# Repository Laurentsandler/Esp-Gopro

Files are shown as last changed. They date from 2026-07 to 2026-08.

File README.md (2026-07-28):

# ESP32-P4 GO-Pro


## Overview

A compact, 3D-printed, battery-powered portable camera based on the Waveshare ESP32-P4 module.

**Motivation:**
I wanted to build a small action camera that can record me biking, among other cool stuff. I initally wanted to make a custom pcb, but the esp32 p4 is not yet available for pcba assembly.

## Usage

1. Connect the battery to the charger board, and connect the charger board to the mainboard.
2. Press the flex boot button to capture photos or start/stop recording.
3. Recharge using the USB-C port(on the charger board).

---

## Hardware & CAD

The custom enclosure was designed in Onshape. 

* **CAD Files:** https://cad.onshape.com/documents/a52dcf8d564a68f7811ecbec/w/4524fd8eb7e4bb6c92c5f085/e/23b7f0b571128349549216fd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

### Images

 **3D Model Assembly:** 

 **Case Details:** 

 **Wiring Diagram:** 
 
---

## Assembly Instructions

 1. To print the case, use a 0.2 mm layer height. You can use any material, but PLA or PLA silk is preferred due to its dimensional accuracy. With 15% infill being enough for structural integrity. 

 2. To assemble the device, first wire all of the components together as shown in the wiring diagram making sure to carefully connect the camera with its ribbon connector into the camera connection slot on the main board then push the camera into its press-fit hole and push in the main ESP32-P4 board on top of it. you may then use tape or double-sided tape to secure the battery to the main board and to push the small charging board into its USB-C hole. This is enough to hold it down. Then finally, you may snap on the back lid. 
 
---

## Bill of Materials (BOM)

A complete `bom.csv` is included in the repository (`docs/BOM.csv`). Primary components include:

| Component | Description | Qty | Price (USD) | Source |
| :--- | :--- | :--- | :--- | :--- |
| **Microcontroller** | Waveshare ESP32-P4 Module (w/ camera connector) | 1 | ~$21.89 | [Amazon](https://amzn.eu/d/0bZVOaVJ) |
| **Camera** | Compatible Camera Module | 1 | ~$9.44 | [AliExpress](https://fr.aliexpress.com/item/1005004540834095.html) |
| **Battery** | LiPo Battery | 1 | ~$9.67 | [AliExpress](https://fr.aliexpress.com/item/1005009589383276.html) |
| **Power Management** | Battery Charging Module | 1 | ~$1.01 | [AliExpress](https://fr.aliexpress.com/item/1005005037876729.html) |

---

## Firmware & Software

The firmware targets the ESP-IDF framework directly (not Arduino — ESP32-P4 Arduino/PlatformIO-Arduino support is still unstable, Espressif itself recommends ESP-IDF for this chip at this stage). It's built with [PlatformIO](https://platformio.org/), which wraps ESP-IDF's build system for you.

**Prerequisites:**
* [PlatformIO](https://platformio.org/install) (CLI or the VS Code extension)
* That's it locally — PlatformIO downloads the ESP-IDF toolchain itself on first build.

**Dependencies:**
This project uses Espressif's official camera/video stack for the ESP32-P4, declared in [`src/idf_component.yml`](Firmware/src/idf_component.yml) and pulled automatically by the IDF Component Manager on first build (no manual download needed):
* [`espressif/esp_video`](https://components.espressif.com/components/espressif/esp_video) — V4L2-compatible camera driver framework for the ESP32-P4's MIPI-CSI interface. Transitively brings in `esp_cam_sensor` (OV5647 sensor driver), `esp_ipa` (image processing/AE/AWB), and `esp_sccb_intf` (camera control bus).
* [`espressif/esp_h264`](https://components.espressif.com/components/espressif/esp_h264) — hardware-accelerated H.264 encoder, used to encode video on the fly while recording.
* Everything else (FATFS, SDMMC host driver, GPIO, deep sleep) ships as part of ESP-IDF itself — no extra install.

**Building & flashing:**
```bash
cd Firmware
pio run              # build
pio run -t upload    # flash over USB-C
pio device monitor    # serial log at 115200 baud
```

**How it works:** the board deep-sleeps between button presses to save battery. A single click on BOOT starts recording (click again to stop); three clicks within 800 ms takes a photo. See the comment block at the top of `src/main.cpp` for the handful of hardware-specific details (exact button GPIO, deep-sleep wakeup API) worth double-checking against your specific board revision before you rely on it.

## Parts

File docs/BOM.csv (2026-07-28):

Component | Description | Quantity | Price (USD) | Link
Microcontroller | Waveshare ESP32-P4 module with camera connector | 1 | 21.89 | https://amzn.eu/d/0bZVOaVJ
Camera | Camera module | 1 | 9.44 | https://fr.aliexpress.com/item/1005004540834095.html?mp=1
Battery | LiPo Battery | 1 | 9.67 | https://fr.aliexpress.com/item/1005009589383276.html?mp=1
Power Management | Battery charging module | 1 | 1.10 | https://fr.aliexpress.com/item/1005005037876729.html?mp=1

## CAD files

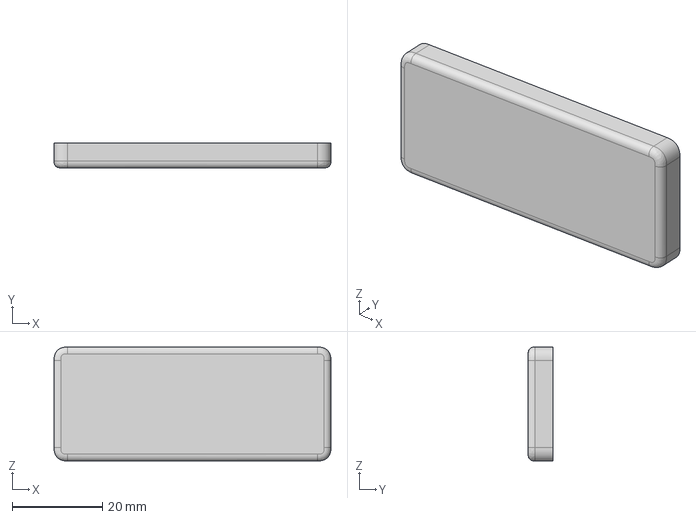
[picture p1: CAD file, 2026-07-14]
CAD/Lid.step
61.5 x 5.50 x 25.3 mm

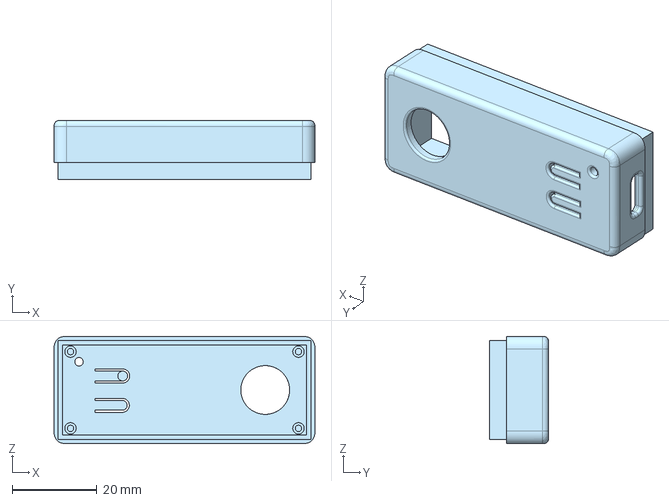
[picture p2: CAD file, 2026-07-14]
CAD/Case.step
61.5 x 14.0 x 25.3 mm

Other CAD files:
CAD/Case.stl
CAD/Lid.stl

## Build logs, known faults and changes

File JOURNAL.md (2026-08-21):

---

title: "DIY ESP32-P4 GoPro"
author: "Laurent Sandler"
description: "Development journal for a DIY ESP32-P4 GoPro"
created_at: "2026-06-19"
------------------------

# June 19: Created the concept and picked parts

Why the ESP32-P4 at all

I picked the P4 over the ESP32-S3 because I needed the ability to record video at a usable frame rate and quality, this requires a hardware video encoder and well as MIPI_CSI input, This is enough for video at 1080p30. The tradeoff i'm going to have the accept is no native wifi support without a sister ESP32-C6 chip.

The custom PCB endeavor

My first plan was a custom PCB with a bare ESP32-P4 module, so I could put the camera connector, charger, and battery management on a single board sized exactly to the case. I spent about ~10 minutes in JLCPCB's parts library searching, before I found out that that the ESP32-P4 isn't stocked for assembly yet.
and dealing with soldering under pcb pins is a headache, so I had to resort to a prebuilt module.

I found this Waveshare ESP32-P4 module with a camera connector.

Waveshare ESP32-P4 module

Finding a suitable camera was trickier, as this board does not have a standard OV5640 connector, it uses one similar to the one on a raspberry pi 02w. So I needed a compatible camera.

Camera

For the battery, I wanted it to fit directly behind the footprint of the main board. I found one that should give me approximately 1.5–2 hours of runtime at 1080p @ 30 FPS.

Battery

I also needed a battery charging module.

Battery charging module

**Total time spent:** 1 hour

# June 19: Designed the case

I designed the case in Onshape, with flex buttons for the reset and boot buttons. The boot button will serve as the only interactive button. I also added holes for the onboard microphone, camera, and USB-C charging port, as well as a snap-on lid. Rather than mounting physical switches, I made the reset and boot buttons as hinge flexures in the case wall, which are thin sections of plastic that bend enough to press the board's onboard tactile switches.

The boot button doubles as the only user control: start/stop recording, and to take photos. Reset stays the same. The chip is kept in a low power state until the button is pressed to start recording or too take a photo.

Case design

Case design

Case design

Case design

**Total time spent:** 4.5 hours

# August 7: Created the Git repository

I spent some time documenting everything about the project and build inside the README file in the repository. I also uploaded all of the files from Onshape, as well as the code. I created a BOM and drew a wiring diagram.

Wiring diagram

Project files

**Total time spent:** 2.5 hours

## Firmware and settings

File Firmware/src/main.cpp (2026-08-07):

#include <stdio.h>
#include <string.h>
#include <fcntl.h>
#include <unistd.h>
#include <sys/ioctl.h>

#include "freertos/FreeRTOS.h"
#include "freertos/task.h"

#include "esp_log.h"
#include "esp_err.h"
#include "esp_sleep.h"
#include "esp_timer.h"
#include "esp_heap_caps.h"
#include "driver/gpio.h"

#include "esp_vfs_fat.h"
#include "sdmmc_cmd.h"
#include "driver/sdmmc_host.h"

#include "linux/videodev2.h"   // V4L2 types/ioctls - esp_video is V4L2-compatible
#include "esp_video_init.h"    // board/sensor bring-up -> registers /dev/videoX
#include "esp_h264_enc.h"      // hardware H.264 encoder

// ---------------------------------------------------------------------------
// Config
// ---------------------------------------------------------------------------

#define BOOT_BUTTON_PIN     GPIO_NUM_35   // TODO: confirm against board schematic
#define TAG                 "CUSTOM_GOPRO"

#define CAMERA_DEV_PATH     "/dev/video0"
#define SD_MOUNT_POINT      "/sdcard"
#define PHOTO_PATH          SD_MOUNT_POINT "/GOPRO_IMG.jpg"
#define VIDEO_PATH          SD_MOUNT_POINT "/GOPRO_VID.h264"

#define PHOTO_WIDTH         2592
#define PHOTO_HEIGHT        1944   // OV5647 max resolution

#define VIDEO_WIDTH         1280
#define VIDEO_HEIGHT        720
#define VIDEO_FPS           30

#define MULTI_CLICK_WINDOW_US   800000   // 800 ms window for triple-click

typedef enum { ACTION_NONE, ACTION_RECORD, ACTION_PHOTO } gopro_action_t;

static sdmmc_card_t *s_sd_card = NULL;

// ---------------------------------------------------------------------------
// Button helpers
// ---------------------------------------------------------------------------

static inline bool button_pressed(void)
{
    return gpio_get_level(BOOT_BUTTON_PIN) == 0; // active-low button to GND
}

static void wait_for_release(void)
{
    while (button_pressed()) {
        vTaskDelay(pdMS_TO_TICKS(20));
    }
    vTaskDelay(pdMS_TO_TICKS(50)); // debounce
}

static void init_button_gpio(void)
{
    gpio_config_t io_conf = {
        .pin_bit_mask = 1ULL << BOOT_BUTTON_PIN,
        .mode         = GPIO_MODE_INPUT,
        .pull_up_en   = GPIO_PULLUP_ENABLE,
        .pull_down_en = GPIO_PULLDOWN_DISABLE,
        .intr_type    = GPIO_INTR_DISABLE,
    };
    gpio_config(&io_conf);
}

/**
 * Figures out what the user wants based on how many times BOOT was clicked
 * within MULTI_CLICK_WINDOW_US of waking the board up.
 *   1 click  -> ACTION_RECORD
 *   3+ clicks -> ACTION_PHOTO
 * Returns ACTION_NONE if we didn't wake up because of the button at all
 * (e.g. first power-on, brown-out reset).
 */
static gopro_action_t detect_action(void)
{
    esp_sleep_wakeup_cause_t cause = esp_sleep_get_wakeup_cause();
    if (cause != ESP_SLEEP_WAKEUP_GPIO && cause != ESP_SLEEP_WAKEUP_EXT0) {
        return ACTION_NONE;
    }

    // The press that woke us is still being held (that's *why* we woke up).
    // Wait it out first so the loop below doesn't double-count it.
    wait_for_release();

    int click_count = 1; // the wake press itself counts as click #1
    int64_t start_time = esp_timer_get_time();

    while (esp_timer_get_time() - start_time < MULTI_CLICK_WINDOW_US) {
        if (button_pressed()) {
            click_count++;
            wait_for_release();
        }
    }

    ESP_LOGI(TAG, "Detected %d click(s)", click_count);
    return (click_count >= 3) ? ACTION_PHOTO : ACTION_RECORD;
}

// ---------------------------------------------------------------------------
// SD card
// ---------------------------------------------------------------------------

static esp_err_t init_sd_card(void)
{
    ESP_LOGI(TAG, "Mounting SD card at %s", SD_MOUNT_POINT);

    sdmmc_host_t host = SDMMC_HOST_DEFAULT();
    sdmmc_slot_config_t slot_config = SDMMC_SLOT_CONFIG_DEFAULT();

    esp_vfs_fat_mount_config_t mount_config = {
        .format_if_mount_failed = false,
        .max_files              = 5,
        .allocation_unit_size   = 16 * 1024,
    };

    esp_err_t ret = esp_vfs_fat_sdmmc_mount(SD_MOUNT_POINT, &host, &slot_config,
                                             &mount_config, &s_sd_card);
    if (ret != ESP_OK) {
        ESP_LOGE(TAG, "SD card mount failed (%s)", esp_err_to_name(ret));
    }
    return ret;
}

static void deinit_sd_card(void)
{
    if (s_sd_card) {
        esp_vfs_fat_sdcard_unmount(SD_MOUNT_POINT, s_sd_card);
        s_sd_card = NULL;
    }
}

// ---------------------------------------------------------------------------
// Camera
// ---------------------------------------------------------------------------

static esp_err_t init_camera(void)
{
    esp_video_init_config_t cam_config = {};
    cam_config.sensor_name = "OV5647";
    cam_config.interface   = ESP_VIDEO_IF_MIPI_CSI;

    esp_err_t ret = esp_video_init(&cam_config);
    if (ret != ESP_OK) {
        ESP_LOGE(TAG, "Camera init failed (%s)", esp_err_to_name(ret));
    }
    return ret;
}

/**
 * Captures a single JPEG frame from the camera and writes it to out_path.
 */
static esp_err_t capture_photo(const char *out_path)
{
    int fd = open(CAMERA_DEV_PATH, O_RDWR);
    if (fd < 0) {
        ESP_LOGE(TAG, "Failed to open %s", CAMERA_DEV_PATH);
        return ESP_FAIL;
    }

    struct v4l2_format fmt;
    memset(&fmt, 0, sizeof(fmt));
    fmt.type                = V4L2_BUF_TYPE_VIDEO_CAPTURE;
    fmt.fmt.pix.width       = PHOTO_WIDTH;
    fmt.fmt.pix.height      = PHOTO_HEIGHT;
    fmt.fmt.pix.pixelformat = V4L2_PIX_FMT_JPEG;

    if (ioctl(fd, VIDIOC_S_FMT, &fmt) != 0) {
        ESP_LOGE(TAG, "VIDIOC_S_FMT failed for photo capture");
        close(fd);
        return ESP_FAIL;
    }

    size_t buf_size = fmt.fmt.pix.sizeimage
                           ? fmt.fmt.pix.sizeimage
                           : (size_t)(PHOTO_WIDTH * PHOTO_HEIGHT / 2);

    uint8_t *frame = (uint8_t *)heap_caps_malloc(buf_size, MALLOC_CAP_8BIT | MALLOC_CAP_SPIRAM);
    if (!frame) {
        close(fd);
        return ESP_ERR_NO_MEM;
    }

    // On a READWRITE-capable V4L2 device the first read() implicitly starts
    // streaming - no explicit VIDIOC_STREAMON needed for single-shot capture.
    ssize_t n = read(fd, frame, buf_size);

    esp_err_t ret = ESP_OK;
    if (n <= 0) {
        ESP_LOGE(TAG, "Camera read() failed while taking photo");
        ret = ESP_FAIL;
    } else {
        FILE *f = fopen(out_path, "wb");
        if (!f) {
            ESP_LOGE(TAG, "Could not open %s for writing", out_path);
            ret = ESP_FAIL;
        } else {
            fwrite(frame, 1, n, f);
            fclose(f);
            ESP_LOGI(TAG, "Photo saved: %s (%d bytes)", out_path, (int)n);
        }
    }

    heap_caps_free(frame);
    close(fd);
    return ret;
}

/**
 * Records raw frames from the camera, encodes them to H.264 in hardware,
 * and streams the result to out_path. Recording stops as soon as BOOT is
 * clicked again.
 */
static esp_err_t record_video(const char *out_path)
{
    int fd = open(CAMERA_DEV_PATH, O_RDWR);
    if (fd < 0) {
        ESP_LOGE(TAG, "Failed to open %s", CAMERA_DEV_PATH);
        return ESP_FAIL;
    }

    struct v4l2_format fmt;
    memset(&fmt, 0, sizeof(fmt));
    fmt.type                = V4L2_BUF_TYPE_VIDEO_CAPTURE;
    fmt.fmt.pix.width       = VIDEO_WIDTH;
    fmt.fmt.pix.height      = VIDEO_HEIGHT;
    fmt.fmt.pix.pixelformat = V4L2_PIX_FMT_YUYV; // esp_h264 accepts YUYV/IYUV raw input

    if (ioctl(fd, VIDIOC_S_FMT, &fmt) != 0) {
        ESP_LOGE(TAG, "VIDIOC_S_FMT failed for video recording");
        close(fd);
        return ESP_FAIL;
    }

    size_t frame_size = fmt.fmt.pix.sizeimage
                             ? fmt.fmt.pix.sizeimage
                             : (size_t)(VIDEO_WIDTH * VIDEO_HEIGHT * 2); // YUYV = 2 B/px

    esp_h264_enc_cfg_t enc_cfg = DEFAULT_H264_ENCODER_CONFIG();
    enc_cfg.width  = VIDEO_WIDTH;
    enc_cfg.height = VIDEO_HEIGHT;
    enc_cfg.fps    = VIDEO_FPS;

    esp_h264_enc_handle_t encoder = NULL;
    if (esp_h264_enc_open(&enc_cfg, &encoder) != ESP_H264_ERR_OK) {
        ESP_LOGE(TAG, "Failed to open H.264 encoder");
        close(fd);
        return ESP_FAIL;
    }

    FILE *out = fopen(out_path, "wb");
    if (!out) {
        ESP_LOGE(TAG, "Could not open %s for writing", out_path);
        esp_h264_enc_close(encoder);
        esp_h264_enc_del(encoder);
        close(fd);
        return ESP_FAIL;
    }

    uint8_t *raw_buf = (uint8_t *)heap_caps_aligned_alloc(16, frame_size,
                                                           MALLOC_CAP_8BIT | MALLOC_CAP_SPIRAM);
    if (!raw_buf) {
        fclose(out);
        esp_h264_enc_close(encoder);
        esp_h264_enc_del(encoder);
        close(fd);
        return ESP_ERR_NO_MEM;
    }

    ESP_LOGI(TAG, "Recording started: %s", out_path);
    int frame_count = 0;

    while (1) {
        ssize_t n = read(fd, raw_buf, frame_size);
        if (n <= 0) {
            ESP_LOGW(TAG, "Camera read() returned %d, stopping recording", (int)n);
            break;
        }

        esp_h264_raw_frame_t in_frame;
        memset(&in_frame, 0, sizeof(in_frame));
        in_frame.raw_data.buffer = raw_buf;
        in_frame.raw_data.len    = n;
        in_frame.pts             = frame_count * (1000 / VIDEO_FPS);

        esp_h264_enc_frame_t out_frame;
        memset(&out_frame, 0, sizeof(out_frame));

        if (esp_h264_enc_process(encoder, &in_frame, &out_frame) == ESP_H264_ERR_OK) {
            for (size_t layer = 0; layer < out_frame.layer_num; layer++) {
                fwrite(out_frame.layer_data[layer].buffer, 1,
                       out_frame.layer_data[layer].len, out);
            }
        }

        frame_count++;

        // A fresh press here means "stop recording".
        if (button_pressed()) {
            wait_for_release();
            ESP_LOGI(TAG, "Stop button detected, ending recording");
            break;
        }
    }

    heap_caps_free(raw_buf);
    fclose(out);
    esp_h264_enc_close(encoder);
    esp_h264_enc_del(encoder);
    close(fd);

    ESP_LOGI(TAG, "Recording saved: %s (%d frames)", out_path, frame_count);
    return ESP_OK;
}

// ---------------------------------------------------------------------------
// Action dispatch + sleep
// ---------------------------------------------------------------------------

static void execute_action(gopro_action_t action)
{
    switch (action) {
        case ACTION_PHOTO:
            ESP_LOGI(TAG, "Taking photo...");
            capture_photo(PHOTO_PATH);
            break;

        case ACTION_RECORD:
            ESP_LOGI(TAG, "Toggling video recording...");
            record_video(VIDEO_PATH);
            break;

        case ACTION_NONE:
        default:
            ESP_LOGI(TAG, "No button action detected, nothing to do");
            break;
    }
}

static void configure_wakeup_and_sleep(void)
{
    // See note (2) at the top of this file: esp32p4 wakes from deep sleep
    // via the newer chip-agnostic GPIO wakeup API rather than ext0/ext1.
    esp_deep_sleep_enable_gpio_wakeup(1ULL << BOOT_BUTTON_PIN, ESP_GPIO_WAKEUP_GPIO_LOW);

    ESP_LOGI(TAG, "Going to sleep - press the button to wake up");
    esp_deep_sleep_start();
}

extern "C" void app_main(void)
{
    init_button_gpio();

    ESP_LOGI(TAG, "Boot, wakeup cause = %d", esp_sleep_get_wakeup_cause());

    gopro_action_t action = detect_action();

    if (action != ACTION_NONE) {
        if (init_sd_card() == ESP_OK) {
            if (init_camera() == ESP_OK) {
                execute_action(action);
            }
            deinit_sd_card();
        }
    }

    configure_wakeup_and_sleep();
}

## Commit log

2026-07-14 Rename Case Part Studio 1 (2).stl to Case.stl
    [Case.stl]
2026-07-14 Rename Case Step Part Studio 1 (1).step to Case.step
    [Case.step]
2026-07-14 Rename Lid (2).step to Lid.step
    [Lid.step]
2026-07-14 Rename Lid Part Studio 1 (2).stl to Lid.stl
    [Lid.stl]
2026-07-27 Revise BOM format to add quantity and price
    Updated BOM to include quantity and price information for components.
    [BOM.csv]
2026-07-27 Revise README with BOM details and firmware info
    Updated Bill of Materials with quantity and price details. Enhanced firmware section with PlatformIO prerequisites and dependencies.
2026-07-27 Update Microcontroller price in BOM.csv
    Updated the price of the Microcontroller in the BOM.
    [BOM.csv]
2026-08-26 Document design considerations for case features
    Added design thought process and details regarding hinge flexures, snap-fit lid, and cutouts for camera, microphone, and USB-C.
2026-08-26 Update README with wiring instructions and specifications
    Added wiring section with interconnect method and battery connection details.
